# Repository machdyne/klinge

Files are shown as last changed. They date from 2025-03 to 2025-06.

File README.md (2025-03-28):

# Klinge Computer

Klinge is an FPGA computer designed by Lone Dynamics Corporation.

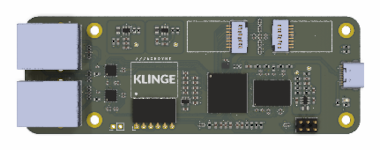
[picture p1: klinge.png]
Klinge


This repo contains schematics, PCB layouts, pinouts, a 3D-printable case, example gateware and documentation.

The 3D enclosure fits into a [Half10](https://github.com/machdyne/half10) compute bay, which can be used stand-alone or attached to a 10" rack.

Find more information on the [Klinge product page](https://machdyne.com/product/klinge-computer/).

## Programming Klinge

Klinge has a JTAG interface and ships with a [DFU bootloader](https://github.com/machdyne/tinydfu-bootloader) that allows the included flash [MMOD](https://machdyne.com/product/mmod) to be programmed over the USB-C port.

### DFU

The DFU bootloader is available for 5 seconds after power-on, issuing a DFU command during this period will stop the boot process until the DFU device is detached. If no command is received the boot process will continue and the user gateware will be loaded.

Install [dfu-util](http://dfu-util.sourceforge.net) (Debian/Ubuntu):

```
$ sudo apt install dfu-util
```

Update the user gateware on the flash MMOD:

```
$ sudo dfu-util -a 0 -D image.bit
```

Detach the DFU device and continue the boot process:

```
$ sudo dfu-util -a 0 -e
```

It is possible to update the bootloader itself using DFU but you shouldn't attempt this unless you have a JTAG programmer (or another method to program the MMOD) available, in case you need to restore the bootloader.

### JTAG

These examples assume you're using a "USB Blaster" JTAG cable, see the header pinout below. You will need to have [openFPGALoader](https://github.com/trabucayre/openFPGALoader) installed.

Program the configuration SRAM:

```
openFPGALoader -c usb-blaster image.bit
```

Program the flash MMOD:

```
openFPGALoader -f -c usb-blaster images/bootloader/tinydfu_klinge.bit
```

## Blinky 

Building the blinky example requires [Yosys](https://github.com/YosysHQ/yosys), [nextpnr-ecp5](https://github.com/YosysHQ/nextpnr) and [Project Trellis](https://github.com/YosysHQ/prjtrellis).

Assuming they are installed, you can simply type `make` to build the gateware, which will be written to output/blinky.bin. You can then use [openFPGALoader](https://github.com/trabucayre/openFPGALoader) or dfu-util to write the gateware to the device.

## Linux

See the [Kakao Linux](https://github.com/machdyne/kakao) repo for the latest instructions.

### Prebuilt Images

Copy the files from the `images/linux` directory to the root directory of a FAT-formatted MicroSD card.

Klinge ships with LiteX gateware on the user gateware section of the MMOD that is compatible with these images. After several seconds the Linux penguin should appear on the screen (HDMI) followed by a login prompt.

### Building Linux

Please follow the setup instructions in the [linux-on-litex-vexriscv](https://github.com/litex-hub/linux-on-litex-vexriscv) repo and then:

1. Build the Linux-capable gateware:

```
$ cd linux-on-litex-vexriscv
$ ./make.py --board klinge --uart-baudrate 115200 --build

$ ls build/klinge
```

2. Write the gateware to the MMOD using USB DFU:

```
$ sudo dfu-util -a 0 -D build/klinge/gateware/klinge.bit
```

3. Copy the device tree binary `build/klinge/klinge.dtb` to a FAT-formatted MicroSD card.

4. Build the Linux kernel and root filesystem:

See the [Kakao Linux](https://github.com/machdyne/kakao?tab=readme-ov-file#optional-building-kakao-linux) repo for instructions.

5. Copy the Image and rootfs.cpio files generated in the previous step to the boot partition of the MicroSD card, in addition to the following files:

6. Copy the OpenSBI binary (included in this repo as `klinge/images/linux/opensbi.bin`) to the MicroSD card. Alternatively, you can build this binary by following [these instructions](https://github.com/litex-hub/linux-on-litex-vexriscv#-generating-the-opensbi-binary-optional).

7. Copy `klinge/images/linux/boot.json` to the MicroSD card.

8. Power-cycle Klinge. After Linux has finished booting you should see a login prompt on the HDMI display.

## LiteX

### Installing LiteX

If you haven't yet installed LiteX please see the [LiteX quick start guide](https://github.com/enjoy-digital/litex#quick-start-guide) for details on installing LiteX.

### Building Custom Gateware

Build the LiteX gateware:

```
$ cd litex-boards/litex_boards/targets
$ ./machdyne_klinge.py --cpu-type=vexriscv --cpu-variant=lite --sys-clk-freq 40000000 --uart-baudrate 1000000 --uart-name serial --build
```

Program the LiteX gateware to SRAM over JTAG:

```
$ ./machdyne_klinge.py --cable usb-blaster --load
```

Or program the LiteX gateware to flash over DFU:

```
$ sudo dfu-util -a 0 -D build/machdyne_klinge/gateware/machdyne_klinge.bit
```

## JTAG Header

The 3.3V JTAG header can be used to program the FPGA SRAM as well as the MMOD flash memory. It can also be used to provide power (5V) to the board.

```
2 4 6
1 3 5
```

| Pin | Signal |
| --- | --- |
| 1 | TCK |
| 2 | TDI |
| 3 | TDO |
| 4 | TMS |
| 5 | 5V0 |
| 6 | GND |

## Board Revisions

| Revision | Notes |
| --- | ----- |
| V1 | Current production version |

## License

The contents of this repo are released under the [Lone Dynamics Open License](LICENSE.md).

Note: You can use these designs for commercial purposes but we ask that instead of producing exact clones, that you either replace our trademarks and logos with your own or add your own next to ours.

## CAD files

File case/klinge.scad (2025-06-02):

/*
 * Klinge Enclosure
 * Copyright (c) 2025 Lone Dynamics Corporation. All rights reserved.
 *
 * required hardware:
 *  - 4 x M3 x 6mm bolts
 *  - 4 x M3 nuts
 *
 */

$fn = 36;

translate([0,0,0]) klinge();

//color([0.3,0.3,0]) translate([0,20,0]) klinge_stand();
//color([0.3,0.3,0]) translate([0,105,0]) klinge_stand();

module klinge_stand() {
    
    difference() {
        minkowski() {
            translate([10,0,0]) cube([40,30,52], center=true);
            sphere(0.5);
        }
        translate([10,0,0]) cube([23,100,42.5], center=true);
        rotate([90,0,0]) translate([0,0,-50]) cylinder(d=15, h=100);
    }
}

module klinge() {
    
    difference() {
        union() {
            
            // sidewalls
            translate([-0.25,63,0]) cube([3.5,128,42], center=true);
            translate([20,63,0]) cube([2,128,42], center=true);          
            
            // front panel
            translate([10,0,19.75]) cube([20,2,2.5], center=true);
            translate([10,0,0]) cube([20,2,3.5], center=true);            
            translate([10,0,-19.75]) cube([20,2,2.5], center=true);

            translate([3.25,0,0]) cube([3.5,2,42], center=true); 

            // back panel
            translate([10,125.75,16]) cube([20,2.5,10], center=true); 
            translate([10,125.75,-16]) cube([20,2.5,10], center=true); 
    
            // mount pads
            rotate([0,90,0]) translate([16,25+1,1]) cylinder(d=8, h=5, center=true);
            rotate([0,90,0]) translate([-16,25+1,1]) cylinder(d=8, h=5, center=true);
            rotate([0,90,0]) translate([16,(25+90)+1,1]) cylinder(d=8, h=5, center=true);
            rotate([0,90,0]) translate([-16,(25+90)+1,1]) cylinder(d=8, h=5, center=true);
                        
        }
        
        // guide rail
        translate([-1,65,0]) cube([2,130,6], center=true);

        // jtag cutout
        translate([30,100.7+1,-18.5]) cube([23,12.5,10], center=true);

        // bolt holes
        rotate([0,90,0]) translate([16,25+1,0]) cylinder(d=3.5, h=500, center=true);
        rotate([0,90,0]) translate([-16,25+1,0]) cylinder(d=3.5, h=500, center=true);
        rotate([0,90,0]) translate([16,(25+90)+1,0]) cylinder(d=3.5, h=500, center=true);
        rotate([0,90,0]) translate([-16,(25+90)+1,0]) cylinder(d=3.5, h=500, center=true);
 
        // nut holes
        rotate([0,90,0]) translate([16,25+1,-1]) cylinder(d=7, h=4, $fn=6, center=true);
        rotate([0,90,0]) translate([-16,25+1,-1]) cylinder(d=7, h=4, $fn=6, center=true);
        rotate([0,90,0]) translate([16,(25+90)+1,-1]) cylinder(d=7, h=4, $fn=6, center=true);
        rotate([0,90,0]) translate([-16,(25+90)+1,-1]) cylinder(d=7, h=4, $fn=6, center=true);

        // tool holes
        rotate([0,90,0]) translate([16,25+1,30]) cylinder(d=7, h=50, center=true);
        rotate([0,90,0]) translate([-16,25+1,30]) cylinder(d=7, h=50, center=true);
        rotate([0,90,0]) translate([16,(25+90)+1,30]) cylinder(d=7, h=50, center=true);
        rotate([0,90,0]) translate([-16,(25+90)+1,30]) cylinder(d=7, h=50, center=true);

        
    }
}

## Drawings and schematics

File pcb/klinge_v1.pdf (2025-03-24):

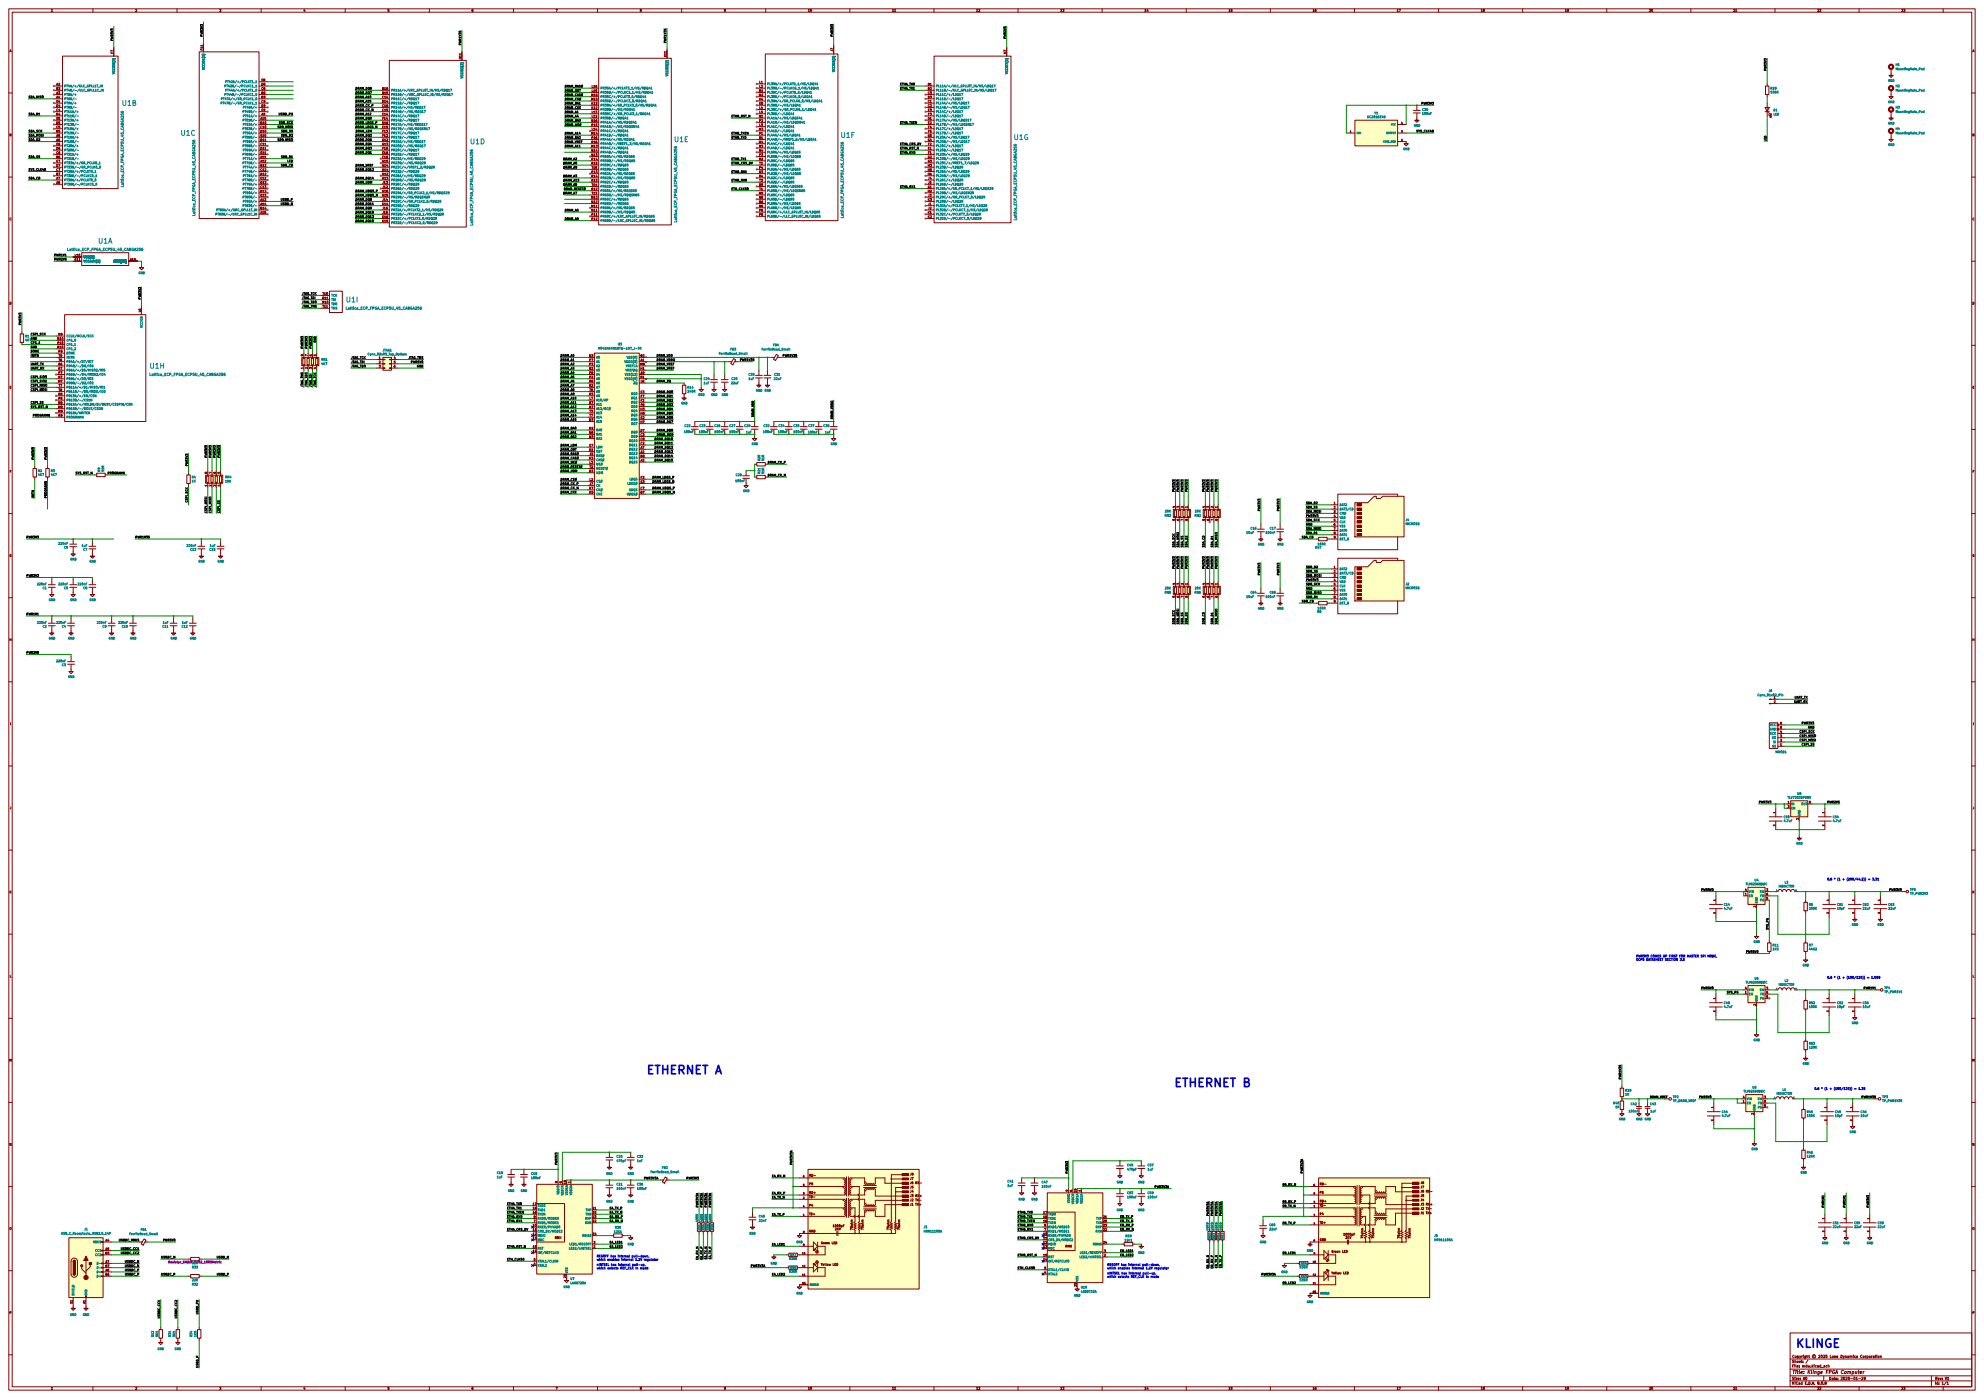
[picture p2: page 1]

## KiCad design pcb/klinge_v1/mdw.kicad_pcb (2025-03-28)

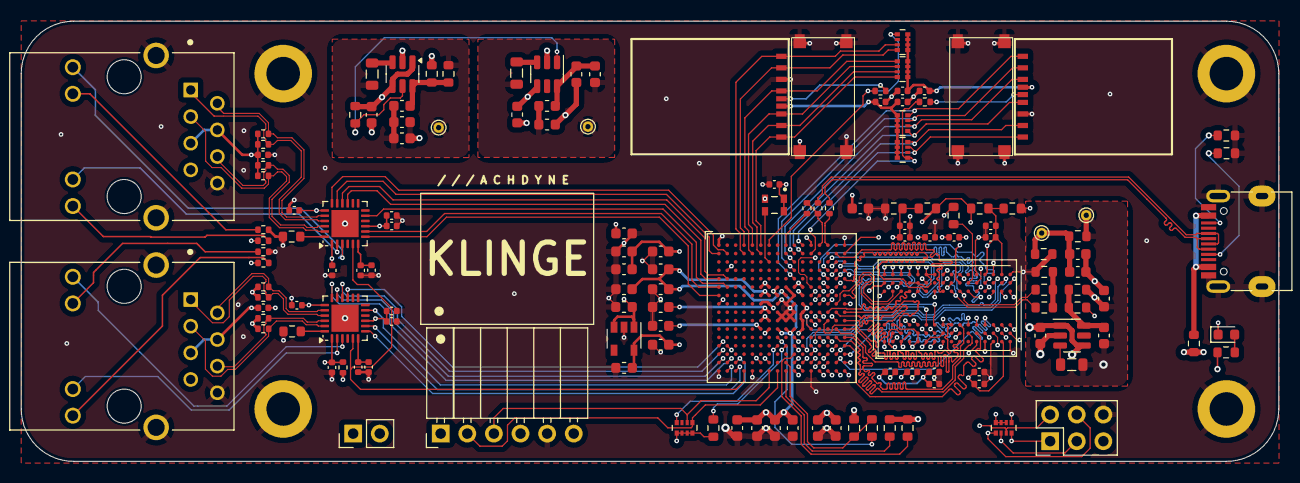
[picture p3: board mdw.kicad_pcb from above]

Board: 6 copper layers, 120.0 x 42.0 mm, 143 parts (0 on the bottom side), 145 nets.

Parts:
C1, C2, C3, C4, C5, C6, C8, C9, C10, C13: 220nF; C_0603_1608Metric
C7, C11, C12, C15, C43: 1uF; C_0603_1608Metric
C14, C44, C48, C50, C54: 4.7uF; C_0603_1608Metric
C16, C64: 10uF; C_0402_1005Metric
C17, C19, C21, C22, C23, C26, C27, C32, C34, C35, C36, C37, C39, C47, C53, C59, C65: 100nF; C_0402_1005Metric
C18, C24, C29, C30, C33, C38, C41, C57: 1uF; C_0402_1005Metric
C20, C49: 470pF; C_0402_1005Metric
C25, C31: 22uF; R_0603_1608Metric
C28: 100nF; R_0603_1608Metric
C40, C60: 22nF; C_0402_1005Metric
C42: 100nF; C_0603_1608Metric
C45, C52, C61: 10pF; C_0603_1608Metric
C46, C56: 10uF; C_0603_1608Metric
C51, C55, C58, C62, C63: 22uF; C_0603_1608Metric
D1: LED; LED_0603_1608Metric
FB1, FB3, FB4: FerriteBead_Small; R_0603_1608Metric
FB2: FerriteBead_Small; R_0402_1005Metric
H1, H2, H3, H4: MountingHole_Pad; MountingHole_3.2mm_M3_ISO14580_Pad
J1: USB_C_Receptacle_USB2.0_14P; USB_C_Receptacle_HRO_TYPE-C-31-M-12-BIG-PADS-PASTE
J2, J4: MICROSD; TF-018B-H15-HAND-SOLDER
J3, J5: HR911105A; HANRUN_HR911105A
J6: Conn_01x02_Pin; PinHeader_1x02_P2.54mm_Vertical
JTAG1: Conn_02x03_Top_Bottom; PinHeader_2x03_P2.54mm_Vertical
L1, L2, L3: INDUCTOR; L_0805_2012Metric
MMOD1: PMOD-Device-x1-Type-2-SPI; MMOD_Host_Socket
R1, R2, R3: 4K7; R_0603_1608Metric
R4, R39, R40: 1K; R_0603_1608Metric
R6: 200K; R_0603_1608Metric
R7: 44K2; R_0603_1608Metric
R8, R47: 100R; R_0402_1005Metric
R9, R20, R21: 51R; R_0603_1608Metric
R11: 1K5; R_0603_1608Metric
R12, R31: 5K1; R_0603_1608Metric
R14: 240R; R_0603_1608Metric
R29: 536R; R_0603_1608Metric
R30, R59: 12K1; R_0603_1608Metric
R32, R33: 22R; R_0402_1005Metric
R34: 1K5; R_0402_1005Metric
R45: 150K; R_0603_1608Metric
R46, R53: 120K; R_0603_1608Metric
R51, R54, R55, R56, R60, R61, R62, R63: 49R9; R_0402_1005Metric
R52: 100K; R_0603_1608Metric
R57, R58, R64, R65: 536R; R_0402_1005Metric
RN1: 4K7; R_Array_Convex_4x0402
RN2, RN3, RN5, RN6: 20K; R_Array_Convex_4x0402
RN4: 10K; R_Array_Convex_4x0402
TP2: TP_DRAM_VREF; TestPoint_THTPad_D1.0mm_Drill0.5mm
TP3: TP_PWR1V35; TestPoint_THTPad_D1.0mm_Drill0.5mm
TP4: TP_PWR1V1; TestPoint_THTPad_D1.0mm_Drill0.5mm
TP5: TP_PWR3V3; TestPoint_THTPad_D1.0mm_Drill0.5mm
U1: Lattice_ECP_FPGA_ECP5U_45_CABGA256; BGA-256_14.0x14.0mm_Layout16x16_P0.8mm_Ball0.45mm_Pad0.32mm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
U3: MT41K64M16TW-107_J-TR; BGA-96_9.0x13.0mm_Layout2x3x16_P0.8mm_FIXED_SILK
U4, U5, U6: TLV62568DDC; SOT-23-6
U7, U10: LAN8720A; QFN-24-1EP_4x4mm_P0.5mm_EP2.6x2.6mm
U8: TLV73325PDBV; SOT-23-5
Y1: KC2016Z48; OSC_KC2016Z13.5600C1KX00

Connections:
/CFG_1: R1.2, U1.P10 (CFG_1)
/CSPI_MISO: MMOD1.3 (SO), RN4.2 (R2.1), U1.T7 (PB11A/+/D1/MISO/IO1)
/CSPI_MOSI: MMOD1.2 (SI), RN4.1 (R1.1), U1.T8 (PB11B/-/D0/MOSI/IO0)
/CSPI_SCK: MMOD1.4 (SCK), R4.2, U1.N9 (CCLK/MCLK/SCK)
/CSPI_SS: MMOD1.1 (SS), RN4.4 (R4.1), U1.N8 (PB15A/+/HOLDN/DI/BUSY/CSSPIN/CEN)
/DRAM_A0: U1.R15 (PR59C/+/RDQ65), U3.N3 (A0)
/DRAM_A1: U1.L13 (PR38C/+/GR_PCLK3_1/RDQ41), U3.P7 (A1)
/DRAM_A2: U1.P14 (PR59B/-/HS/RDQ65), U3.P3 (A2)
/DRAM_A3: U1.R14 (PR62B/-/HS/RDQ65), U3.N2 (A3)
/DRAM_A4: U1.L12 (PR38D/-/RDQ41), U3.P8 (A4)
/DRAM_A5: U1.T14 (PR62D/-/RDQ65), U3.P2 (A5)
/DRAM_A6: U1.N11 (PR68B/-/HS/RDQ65), U3.R8 (A6)
/DRAM_A7: U1.T13 (PR65B/-/HS/RDQSN65), U3.R2 (A7)
/DRAM_A8: U1.P12 (PR68D/-/LRC_GPLL0C_IN/RDQ65), U3.T8 (A8)
/DRAM_A9: U1.T15 (PR59D/-/RDQ65), U3.R3 (A9)
/DRAM_A10: U1.C14 (PR11C/+/RDQ17), U3.L7 (A10/AP)
/DRAM_A11: U1.M13 (PR44C/+/RDQ41), U3.R7 (A11)
/DRAM_A12: U1.E14 (PR14C/+/RDQ17), U3.N7 (A12/BC#)
/DRAM_A13: U1.R13 (PR62C/+/RDQ65), U3.T3 (A13)
/DRAM_A14: U1.M14 (PR41D/-/RDQ41), U3.T7 (A14)
/DRAM_A15: U1.D14 (PR11D/-/RDQ17), U3.M7 (A15)
/DRAM_BA0: U1.N16 (PR41A/+/HS/RDQS41), U3.M2 (BA0)
/DRAM_BA1: U1.K13 (PR38A/+/GR_PCLK3_0/HS/RDQ41), U3.N8 (BA1)
/DRAM_BA2: U1.P16 (PR44A/+/HS/RDQ41), U3.M3 (BA2)
/DRAM_CAS#: U1.M16 (PR35C/+/PCLKT3_0/RDQ41), U3.K3 (CAS#)
/DRAM_CKE: U1.K12 (PR38B/-/HS/RDQ41), U3.K9 (CKE)
/DRAM_CK_N: R21.2, U1.C15 (PR14B/-/HS/RDQ17), U3.K7 (CK#)
/DRAM_CK_P: R20.2, U1.C16 (PR14A/+/HS/RDQ17), U3.J7 (CK)
/DRAM_CS#: U1.M15 (PR35D/-/PCLKC3_0/RDQ41), U3.L2 (CS#)
/DRAM_DQ0: U1.F14 (PR14D/-/RDQ17), U3.E3 (DQ0)
/DRAM_DQ1: U1.E16 (PR20D/-/RDQ17), U3.F7 (DQ1)
/DRAM_DQ2: U1.F12 (PR17D/-/RDQ17), U3.F2 (DQ2)
/DRAM_DQ3: U1.F15 (PR20C/+/RDQ17), U3.F8 (DQ3)
/DRAM_DQ4: U1.G13 (PR20B/-/HS/RDQ17), U3.H3 (DQ4)
/DRAM_DQ5: U1.B16 (PR11A/+/URC_GPLL0T_IN/HS/RDQ17), U3.H8 (DQ5)
/DRAM_DQ6: U1.G12 (PR20A/+/HS/RDQ17), U3.G2 (DQ6)
/DRAM_DQ7: U1.B15 (PR11B/-/URC_GPLL0C_IN/HS/RDQ17), U3.H7 (DQ7)
/DRAM_DQ8: U1.J14 (PR29C/+/GR_PCLK2_0/RDQ29), U3.D7 (DQ8)
/DRAM_DQ9: U1.J16 (PR32A/+/PCLKT2_1/HS/RDQ29), U3.C3 (DQ9)
/DRAM_DQ10: U1.K15 (PR32D/-/PCLKC2_0/RDQ29), U3.C8 (DQ10)
/DRAM_DQ11: U1.K14 (PR29D/-/RDQ29), U3.C2 (DQ11)
/DRAM_DQ12: U1.H14 (PR23D/-/RDQ29), U3.A7 (DQ12)
/DRAM_DQ13: U1.K16 (PR32C/+/PCLKT2_0/RDQ29), U3.A2 (DQ13)
/DRAM_DQ14: U1.H13 (PR26B/-/HS/RDQ29), U3.B8 (DQ14)
/DRAM_DQ15: U1.J15 (PR32B/-/PCLKC2_1/HS/RDQ29), U3.A3 (DQ15)
/DRAM_LDM: U1.F13 (PR17C/+/RDQ17), U3.E7 (LDM)
/DRAM_LDQS_N: U1.E15 (PR17B/-/HS/RDQSN17), U3.G3 (LDQS#)
/DRAM_LDQS_P: U1.D16 (PR17A/+/HS/RDQS17), U3.F3 (LDQS)
/DRAM_ODT: U1.L15 (PR35B/-/PCLKC3_1/HS/RDQ41), U3.K1 (ODT)
/DRAM_RAS#: U1.L16 (PR35A/+/PCLKT3_1/HS/RDQ41), U3.J3 (RAS#)
/DRAM_RESET#: U1.R12 (PR65A/+/HS/RDQS65), U3.T2 (RESET#)
/DRAM_UDM: U1.J13 (PR26C/+/RDQ29), U3.D3 (UDM)
/DRAM_UDQS_N: U1.H15 (PR29B/-/HS/RDQSN29), U3.B7 (UDQS#)
/DRAM_UDQS_P: U1.G16 (PR29A/+/GR_PCLK2_1/HS/RDQS29), U3.C7 (UDQS)
/DRAM_VDD: C22.1, C23.1, C26.1, C27.1, C29.1, C30.1, C31.1, FB4.1, U3.B2 (VDD[9]), U3.D9 (VDD), U3.G7 (VDD), U3.K2 (VDD), U3.K8 (VDD), U3.N1 (VDD), U3.N9 (VDD), U3.R1 (VDD), U3.R9 (VDD)
/DRAM_VDDQ: C24.1, C25.1, C32.1, C34.1, C35.1, C37.1, C38.1, FB3.1, U3.A1 (VDDQ[9]), U3.A8 (VDDQ), U3.C1 (VDDQ), U3.C9 (VDDQ), U3.D2 (VDDQ), U3.E9 (VDDQ), U3.F1 (VDDQ), U3.H2 (VDDQ), U3.H9 (VDDQ)
/DRAM_VREF: C42.1, C43.1, R39.2, R40.1, TP2.1, U1.G14 (PR23C/+/VREF1_2/RDQ29), U1.R16 (PR44B/-/VREF1_3/HS/RDQ41), U3.H1 (VREFDQ), U3.M8 (VREFCA)
/DRAM_WE#: U1.P15 (PR41B/-/HS/RDQSN41), U3.L3 (WE#)
/DRAM_ZQ: R14.1, U3.L8 (ZQ)
/EA_LED1: J3.9, U7.3 (LED1/REGOFF)
/EA_LED2: J3.11, U7.2 (LED2/nINTSEL)
/EA_RX_N: J3.6, R51.2, U7.22 (RXN)
/EA_RX_P: J3.3, R54.2, U7.23 (RXP)
/EA_TX_N: J3.2, R55.2, U7.20 (TXN)
/EA_TX_P: J3.1, R56.2, U7.21 (TXP)
/EB_LED1: J5.9, U10.3 (LED1/REGOFF)
/EB_LED2: J5.11, U10.2 (LED2/nINTSEL)
/EB_RX_N: J5.6, R60.2, U10.22 (RXN)
/EB_RX_P: J5.3, R61.2, U10.23 (RXP)
/EB_TX_N: J5.2, R62.2, U10.20 (TXN)
/EB_TX_P: J5.1, R63.2, U10.21 (TXP)
/ETHA_CRS_DV: U1.F2 (PL20C/+/LDQ17), U7.11 (CRS_DV/MODE2)
/ETHA_RST_N: U1.E1 (PL20D/-/LDQ17), U7.15 (RST)
/ETHA_RX0: U1.F1 (PL23A/+/HS/LDQ29), U7.8 (RXD0/MODE0)
/ETHA_RX1: U1.G1 (PL29A/+/GR_PCLK7_1/HS/LDQS29), U7.7 (RXD1/MODE1)
/ETHA_TX0: U1.B1 (PL11A/+/ULC_GPLL0T_IN/HS/LDQ17), U7.17 (TXD0)
/ETHA_TX1: U1.B2 (PL11B/-/ULC_GPLL0C_IN/HS/LDQ17), U7.18 (TXD1)
/ETHA_TXEN: U1.E2 (PL17B/-/HS/LDQSN17), U7.16 (TXEN)
/ETHB_CRS_DV: U1.T2 (PL59D/-/LDQ65), U10.11 (CRS_DV/MODE2)
/ETHB_RST_N: U1.N1 (PL41A/+/HS/LDQS41), U10.15 (RST)
/ETHB_RX0: U1.T3 (PL62D/-/LDQ65), U10.8 (RXD0/MODE0)
/ETHB_RX1: U1.R3 (PL62B/-/HS/LDQ65), U10.7 (RXD1/MODE1)
/ETHB_TX0: U1.R1 (PL44B/-/VREF1_6/HS/LDQ41), U10.17 (TXD0)
/ETHB_TX1: U1.R2 (PL59C/+/LDQ65), U10.18 (TXD1)
/ETHB_TXEN: U1.P1 (PL44A/+/HS/LDQ41), U10.16 (TXEN)
/ETH_CLK50: U1.T4 (PL65B/-/HS/LDQSN65), U7.5 (XTAL1/CLKIN), U10.5 (XTAL1/CLKIN)
/INITN: R2.2, U1.T9 (INITN)
/JTAG_TCK: JTAG1.1, RN1.4 (R4.1), U1.T10 (TCK)
/JTAG_TDI: JTAG1.2, RN1.3 (R3.1), U1.R11 (TDI)
/JTAG_TDO: JTAG1.3, RN1.2 (R2.1), U1.M10 (TDO)
/JTAG_TMS: JTAG1.4, RN1.1 (R1.1), U1.T11 (TMS)
/LED: D1.1 (K), U1.A12 (PT71B/-)
/PROGRAMN: R3.2, R9.2, U1.R9 (PROGRAMN)
/PWR1V1: C2.2, C4.2, C9.2, C10.2, C11.2, C12.2, C51.1, C52.1, C55.1, C56.1, L2.2, R52.1, TP4.1, U1.G6 (VCC[6]), U1.G7 (VCC[6]), U1.G9 (VCC[6]), U1.L8 (VCC[6]), U1.L9 (VCC[6]), U1.L10 (VCC[6])
/PWR1V35: C13.2, C15.2, C45.1, C46.1, FB3.2, FB4.2, L1.2, R39.1, R45.1, TP3.1, U1.H11 (VCCIO2[2]), U1.J11 (VCCIO2[2]), U1.K11 (VCCIO3[2]), U1.L11 (VCCIO3[2])
/PWR2V5: C3.2, C54.1, U1.G11 (VCCAUX[2]), U1.H6 (VCCIO7[2]), U1.H7 (VCCIO7[2]), U1.L7 (VCCAUX[2]), U8.5 (OUT)
/PWR3V3: C1.2, C5.2, C6.2, C7.2, C8.2, C16.1, C17.1, C18.1, C19.1, C39.1, C41.1, C47.1, C50.1, C58.1, C61.1, C62.1, C63.1, C64.1, C65.1, FB2.2, J2.4 (VDD), J4.4 (VDD), L3.2, MMOD1.6 (VCC), R1.1, R2.1, R3.1, R4.1, R6.1, R29.1, RN1.6 (R3.2), RN1.7 (R2.2), RN1.8 (R1.2), RN2.1 (R1.1), RN2.2 (R2.1), RN2.3 (R3.1), RN2.4 (R4.1), RN3.1 (R1.1), RN3.2 (R2.1), RN3.3 (R3.1), RN3.4 (R4.1), RN4.5 (R4.2), RN4.6 (R3.2), RN4.7 (R2.2), RN4.8 (R1.2), RN5.1 (R1.1), RN5.2 (R2.1), RN5.3 (R3.1), RN5.4 (R4.1), RN6.1 (R1.1), RN6.2 (R2.1), RN6.3 (R3.1), RN6.4 (R4.1), TP5.1, U1.F6 (VCCIO0[2]), U1.F7 (VCCIO0[2]), U1.F10 (VCCIO1[2]), U1.F11 (VCCIO1[2]), U1.J6 (VCCIO6[2]), U1.J7 (VCCIO6[2]), U1.L6 (VCCIO8), U7.9 (VDDIO), U8.1 (IN), U8.3 (EN), U10.9 (VDDIO), Y1.1 (INH), Y1.4 (VCC)
/PWR3V3A: C21.1, C36.1, C40.1, C53.1, C59.1, C60.1, FB2.1, J3.4, J3.5, J5.4, J5.5, R51.1, R54.1, R55.1, R56.1, R58.1, R60.1, R61.1, R62.1, R63.1, R65.1, U7.1 (VDD2A), U7.19 (VDD1A), U10.1 (VDD2A), U10.19 (VDD1A)
/PWR5V0: C14.1, C44.1, C48.1, FB1.2, JTAG1.5, R11.2, U4.1 (EN), U4.4 (VIN), U5.1 (EN), U5.4 (VIN), U6.4 (VIN)
/SDA_CD: R47.1, RN2.5 (R4.2), U1.A7 (PT38A/+/PCLKT0_0)
/SDA_D1: J4.8 (DAT1), RN2.7 (R2.2), U1.B4 (PT11B/-)
/SDA_D2: J4.1 (DAT2), RN3.8 (R1.2), U1.A6 (PT18B/-)
/SDA_MISO: J4.7 (DAT0), RN2.8 (R1.2), U1.A4 (PT6B/-)
/SDA_MOSI: J4.3 (CMD), RN3.6 (R3.2), U1.A5 (PT18A/+)
/SDA_SCK: J4.5 (CLK), RN3.5 (R4.2), U1.B5 (PT15B/-)
/SDA_SS: J4.2 (DAT3/CD), RN3.7 (R2.2), U1.B6 (PT31B/-)
/SDB_CD: R8.1, RN6.5 (R4.2), U1.B12 (PT74A/+)
/SDB_D1: J2.8 (DAT1), RN6.7 (R2.2), U1.A11 (PT71A/+)
/SDB_D2: J2.1 (DAT2), RN5.8 (R1.2), U1.E10 (PT56B/-)
/SDB_MISO: J2.7 (DAT0), RN6.8 (R1.2), U1.B11 (PT58A/+)
/SDB_MOSI: J2.3 (CMD), RN5.6 (R3.2), U1.C10 (PT53B/-)
/SDB_SCK: J2.5 (CLK), RN5.5 (R4.2), U1.B10 (PT53A/+)
/SDB_SS: J2.2 (DAT3/CD), RN5.7 (R2.2), U1.D10 (PT56A/+)
/SYS_CLK48: U1.C7 (PT36A/+/PCLKT0_1), Y1.3 (OUTPUT)
/SYS_PG: R11.1, U4.5 (PG), U6.1 (EN)
/SYS_RST_N: R9.1, U1.M8 (PB15B/-/DOUT/CSON)
/UART_RX: J6.2, U1.R7 (PB6A/+/D5/MISO2/IO5)
/UART_TX: J6.1, U1.R6 (PB4B/-/D6/IO6)
/USBDC_CC1: J1.A5 (CC1), R12.1
/USBDC_CC2: J1.B5 (CC2), R31.1
/USBDC_N: J1.A7 (D-), J1.B7 (D-), R33.1
/USBDC_P: J1.A6 (D+), J1.B6 (D+), R32.1
/USBDC_VBUS: FB1.1, J1.A4 (VBUS), J1.A9 (VBUS), J1.B4 (VBUS), J1.B9 (VBUS)
/USBD_N: R33.2, U1.A14 (PT83B/-)
/USBD_P: R32.2, R34.2, U1.A13 (PT83A/+)
/USBD_PU: R34.1, U1.A9 (PT51A/+)
GND: C1.1, C2.1, C3.1, C4.1, C5.1, C6.1, C7.1, C8.1, C9.1, C10.1, C11.1, C12.1, C13.1, C14.2, C15.1, C16.2, C17.2, C18.2, C19.2, C20.2, C21.2, C22.2, C23.2, C24.2, C25.2, C26.2, C27.2, C28.2, C29.2, C30.2, C31.2, C32.2, C33.2, C34.2, C35.2, C36.2, C37.2, C38.2, C39.2, C40.2, C41.2, C42.2, C43.2, C44.2, C46.2, C47.2, C48.2, C49.2, C50.2, C51.2, C53.2, C54.2, C55.2, C56.2, C57.2, C58.2, C59.2, C60.2, C62.2, C63.2, C64.2, C65.2, H1.1, H2.1, H3.1, H4.1, J1.A1 (GND), J1.A12 (GND), J1.B1 (GND), J1.B12 (GND), J1.S1 (SHIELD), J2.6 (VSS), J3.8, J3.15 (SHIELD), J3.16 (SHIELD), J4.6 (VSS), J5.8, J5.15 (SHIELD), J5.16 (SHIELD), JTAG1.6, MMOD1.5 (GND), R7.2, R12.2, R14.2, R30.1, R31.2, R40.2, R46.2, R53.2, R57.1, R59.1, R64.1, RN1.5 (R4.2), U1.A1 (GND[27]), U1.A16 (GND[27]), U1.D2 (GND[27]), U1.D15 (GND[27]), U1.F8 (GND[27]), U1.F9 (GND[27]), U1.G8 (GND[27]), U1.G10 (GND[27]), U1.H1 (GND[27]), U1.H8 (GND[27]), U1.H9 (GND[27]), U1.H10 (GND[27]), U1.H16 (GND[27]), U1.J8 (GND[27]), U1.J9 (GND[27]), U1.J10 (GND[27]), U1.K6 (GND[27]), U1.K7 (GND[27]), U1.K8 (GND[27]), U1.K9 (GND[27]), U1.K10 (GND[27]), U1.N2 (GND[27]), U1.N10 (CFG_0), U1.N15 (GND[27]), U1.R10 (CFG_2), U1.T1 (GND[27]), U1.T5 (GND[27]), U1.T12 (GND[27]), U1.T16 (GND[27]), U3.A9 (VSS[12]), U3.B1 (VSSQ[9]), U3.B3 (VSS), U3.B9 (VSSQ), U3.D1 (VSSQ), U3.D8 (VSSQ), U3.E1 (VSS), U3.E2 (VSSQ), U3.E8 (VSSQ), U3.F9 (VSSQ), U3.G1 (VSSQ), U3.G9 (VSSQ), U3.J2 (VSS), U3.J8 (VSS), U3.M1 (VSS), U3.M9 (VSS), U3.P1 (VSS), U3.P9 (VSS), U3.T1 (VSS), U3.T9 (VSS), U4.2 (GND), U5.2 (GND), U6.2 (GND), U7.25 (VSS), U8.2 (GND), U10.25 (VSS), Y1.2 (CASE_GND)
unnamed: C28.1, R20.1, R21.1
unnamed: D1.2 (A), R29.2
unnamed: J2.9 (DET_B), R8.2
unnamed: J3.10, R57.2
unnamed: J3.12, R58.2
unnamed: J4.9 (DET_B), R47.2
unnamed: J5.10, R64.2
unnamed: J5.12, R65.2
unnamed: C61.2, R6.2, R7.1, U4.6 (FB)
unnamed: L3.1, U4.3 (SW)
unnamed: C45.2, R45.2, R46.1, U5.6 (FB)
unnamed: L1.1, U5.3 (SW)
unnamed: C52.2, R52.2, R53.1, U6.6 (FB)
unnamed: L2.1, U6.3 (SW)
unnamed: R30.2, U7.24 (RBIAS)
unnamed: C20.1, C33.1, U7.6 (VDDCR)
unnamed: R59.2, U10.24 (RBIAS)
unnamed: C49.1, C57.1, U10.6 (VDDCR)

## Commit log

2025-03-28 add pcb
    [mdw.kicad_pcb, mdw.kicad_sch]
2025-06-02 add klinge stands
    [klinge.scad]

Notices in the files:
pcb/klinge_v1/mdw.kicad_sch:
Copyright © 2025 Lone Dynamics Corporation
